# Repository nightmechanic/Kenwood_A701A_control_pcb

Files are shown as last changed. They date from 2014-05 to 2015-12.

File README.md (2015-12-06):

Kenwood_A701A_control_pcb
=========================

This is a Control PCB for a Kenwood A701A kitchen mixer.

Created for our kitchen mixer restoration project.

Benefits:
  - Allows using a common 470 ohm 25W cement resistor (+ a 2W 10kohm ) instead of the expensive DR type resistor originaly used by Kenwood.
  - Uses terminal blocks for wire connections
  - the components are mounted on the PCB instead of floating around...

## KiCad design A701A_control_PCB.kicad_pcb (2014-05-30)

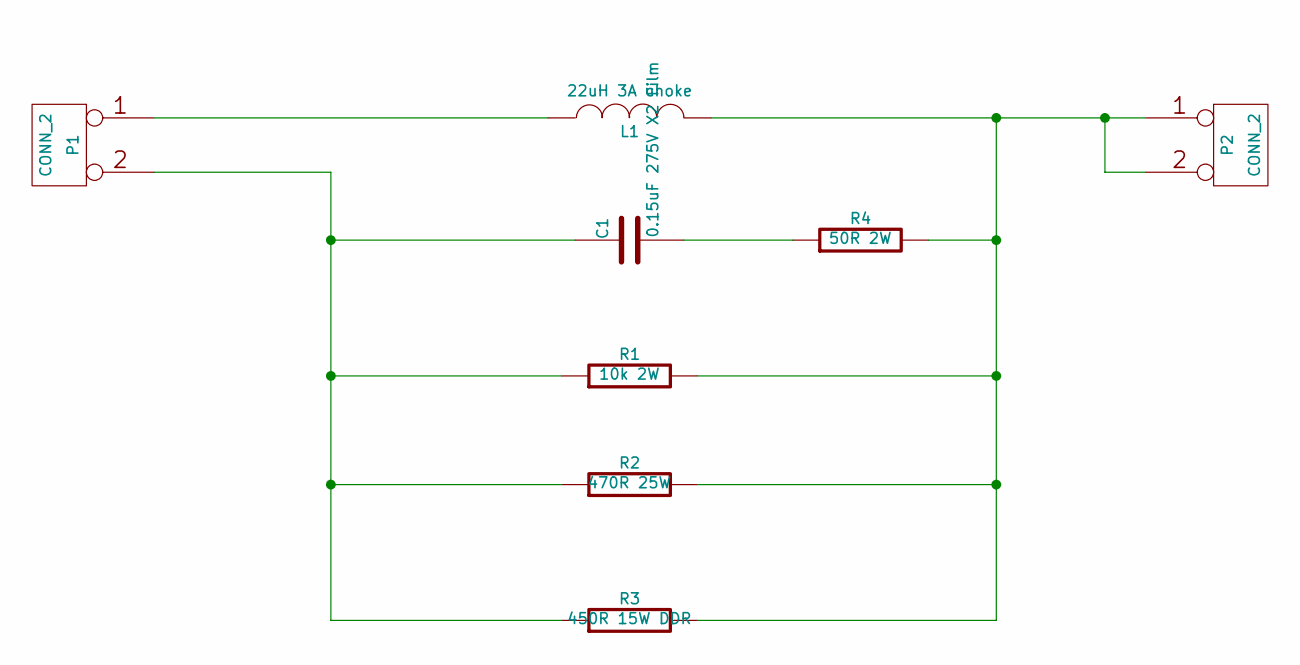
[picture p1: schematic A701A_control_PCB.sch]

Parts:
C1: 0.15uF 275V X2 Film
L1: 22uH 3A choke
P1, P2: CONN_2
R1: 10k 2W
R2: 470R 25W
R3: 450R 15W DDR
R4: 50R 2W

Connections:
unnamed: C1.1, P1.2 (PM), R1.1, R2.1, R3.1
unnamed: C1.2, R4.1
unnamed: L1.1, P1.1
unnamed: L1.2, P2.1, P2.2 (PM), R1.2, R2.2, R3.2, R4.2

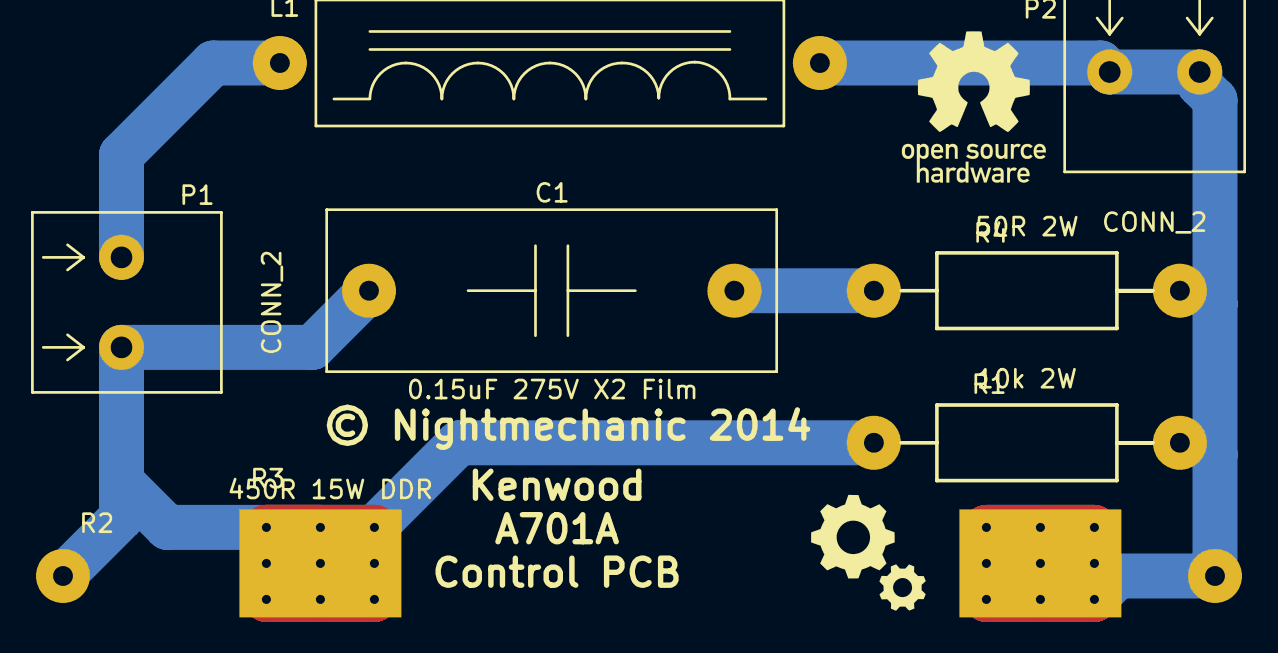
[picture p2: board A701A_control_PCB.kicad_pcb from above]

Board: 2 copper layers, 10 parts (0 on the bottom side), 4 nets.

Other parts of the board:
VAL: REF; Gears_F.SilkS_8mm
VAL#2: REF; OSHW_F.SilkS_8mm

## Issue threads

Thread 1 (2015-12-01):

Guide?

terryb8s, 2015-12-01:
This is awesome, but for someone like me who has no idea of electronics do you have any pics of the completed and soldered PCB? would be interested in a little guide and bill of materials, I know this is asking a lot. I can solder and probably get the PCB created but don't know electronics.

nightmechanic, 2015-12-06:
Hi Terry,

*IMPORTANT: this circuit handles line voltages (230V in my country that are
dangerous, be careful and know what you are doing!*

I am attaching some pictures that I hope will help,

bill of materials: (the links will take you to Mouser's web site where I
got the components)

   - P1, P2 (the connectors/terminal blocks): Phoenix Contact, 1792863
   <https://www.mouser.com/Search/ProductDetail.aspx?R=1792863virtualkey65100000virtualkey651-1792863>
(any
   5mm pitch terminal block (with reasonable pin thickness) should fit, or you
   can directly solder the wires to the PCB)
   - C1 : Kemet 0.15uF 275V X2 film cap. PME271M615KR30
   <https://www.mouser.com/Search/ProductDetail.aspx?R=PME271M615KR30virtualkey64620000virtualkey80-PME271M615KR30>
   - L1: EPCOS/TDK 22uH 3A inductor B82111EC22
   <https://www.mouser.com/Search/ProductDetail.aspx?R=B82111EC22virtualkey59250000virtualkey871-B82111EC22>
   - R1: (Vishay) 10kohm, 2 Watt, 5% resistor PR02000201002JR500
   <https://www.mouser.com/Search/ProductDetail.aspx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>
   - R2: Xicon 470 Ohm 25Watt 5% resistor 280-CR25-470-RC
   <https://www.mouser.com/Search/ProductDetail.aspx?R=280-CR25-470-RCvirtualkey21980000virtualkey280-CR25-470-RC>
(I
   see this is not currently available, any similar resistor (470 ohm, ,
   ~25Watt) should work, just make sure you figure out  how to mechanically
   mount it)
   - R4: Through hole 51 ohm 2Watt resistor - this is optional and depends
   if you currently have one installed in your mixer - I didn't, so as you can
   see it is shorted in the PCB.

In case you have series chokes on the line inputs and you want to replace
them as well these should do the job: 77A-5R6M-01
<https://www.mouser.com/Search/ProductDetail.aspx?R=77A-5R6M-01virtualkey60130000virtualkey434-77A-5R6M-01>

Some notes:

   - The PCB is intended to be the same electrical circuit as Kenwood's
   original circuit, so electrical connections should be the same.
   - The required resistor is a 450 ohm resistor, this is not a standard
   value, and in order to achieve this value I connected 2 resistors in
   parallel: R1 and R3 (a 470 ohm and a 10kOhm resistors) that, together, give
   a close enough value.
   - R3 is a place holder for an "original" type resistor ("DDR" I think is
   the ) that can be soldered directly to the PCB, in this case you do not
   need R2 and if it is the correct value, you do not need R1 either.

I hope this helps, let me know if you have more questions,

Ran

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

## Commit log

2014-05-28 First revision
    Layout almost done (missing board edge
    [A701A_control_PCB-B_Cu.gbl, A701A_control_PCB-B_Mask.gbs, A701A_control_PCB-B_SilkS.gbo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]
2014-05-30 Layout done
    [A701A_control_PCB-B_Cu.gbl, A701A_control_PCB-B_Mask.gbs, A701A_control_PCB-B_SilkS.gbo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]

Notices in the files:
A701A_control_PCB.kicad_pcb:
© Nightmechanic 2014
